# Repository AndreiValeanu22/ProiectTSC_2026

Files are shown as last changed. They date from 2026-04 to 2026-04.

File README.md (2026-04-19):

# InkTime – Proiect TSC 2026

## Rezumat

Acest depozit conține schematica nativă, placa de circuit imprimat, livrabilele de manufacturare, materialele mecanice parțiale și documentația vizuală pentru dispozitivul **InkTime**, aliniate structurii cerute în ghidul de proiect de pe [OCW – Proiect 2026](https://ocw.cs.pub.ro/courses/tsc/proiect2026).

## Galerie imagini

Capturile de mai jos sunt versiunile din directorul `Images/` și se afișează direct în pagina README pe GitHub.

### Schematică (două zone)

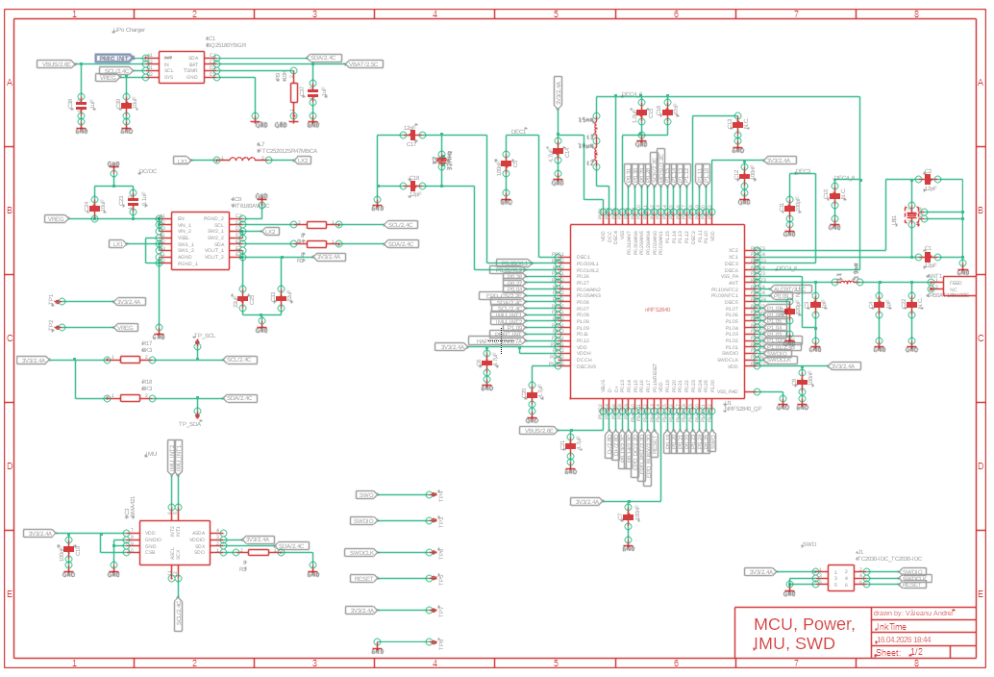
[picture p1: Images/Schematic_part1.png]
Fragment schematică – partea 1


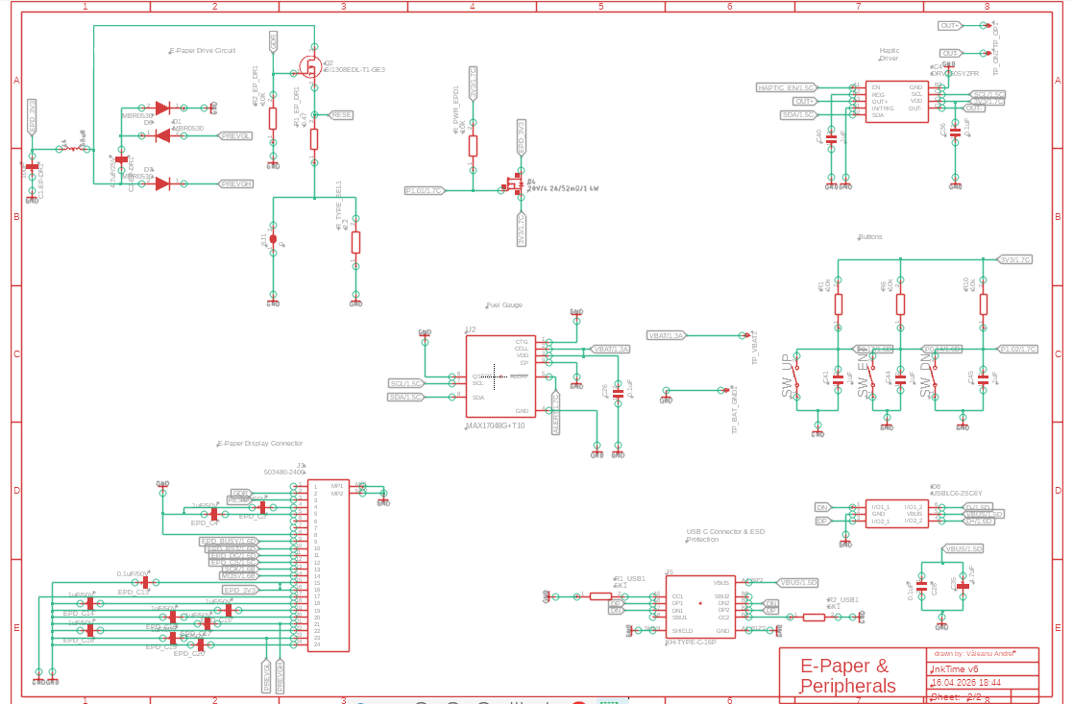
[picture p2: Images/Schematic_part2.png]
Fragment schematică – partea 2


### Placă de circuit imprimat

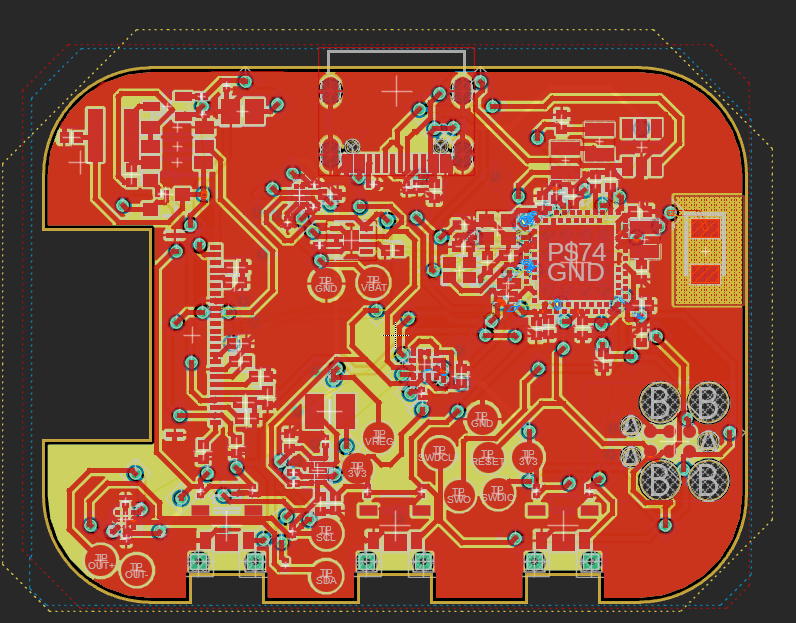
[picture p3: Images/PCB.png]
Vedere PCB


### Previzualizări 3D

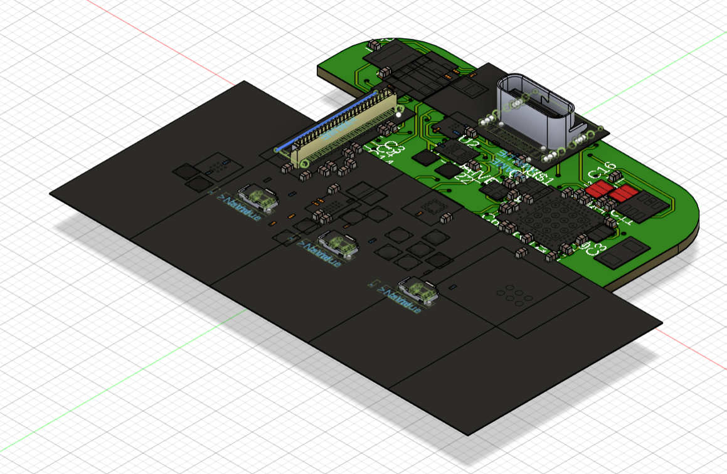
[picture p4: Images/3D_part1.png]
Previzualizare 3D – partea 1


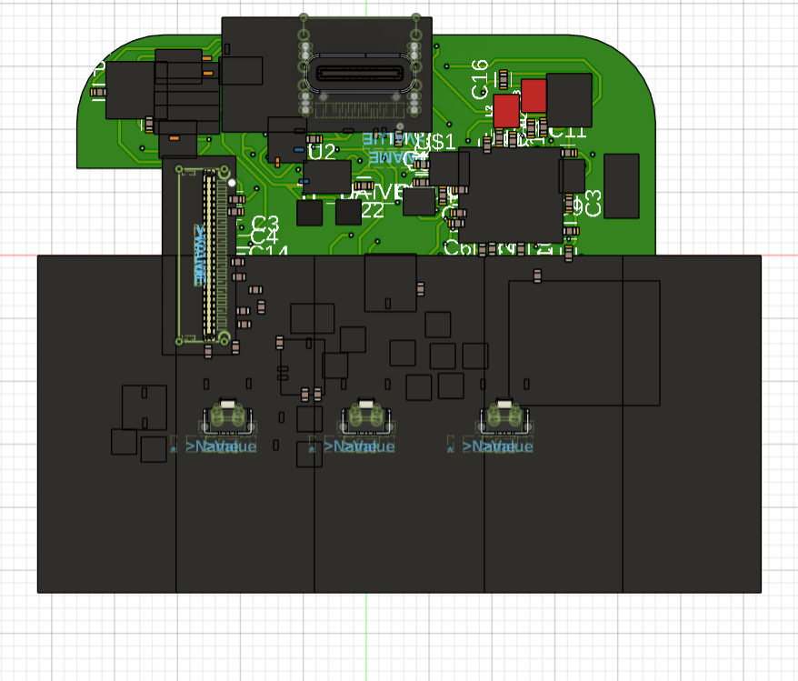
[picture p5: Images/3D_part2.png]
Previzualizare 3D – partea 2


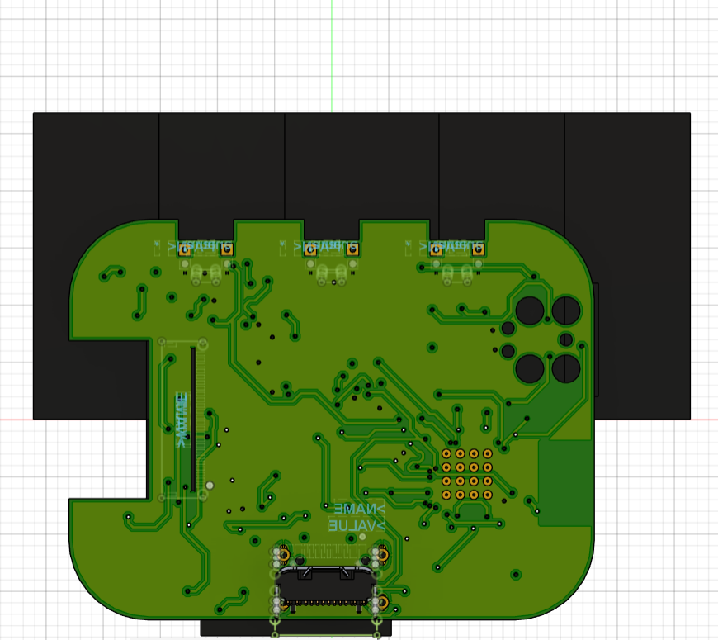
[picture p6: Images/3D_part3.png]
Previzualizare 3D – partea 3


## Conformitate cu structura de încărcare (OCW)

| Cerință OCW | Conținut în acest depozit |
|---|---|
| `Hardware/` – schematic `.sch` | `ProjectTSCEtapa1.sch` |
| `Hardware/` – placă `.brd` | `InkTime v6_PCB_Partea2.brd` |
| `Hardware/` – print schematic `.pdf` | `InkTime_Schematic.pdf` (compus din capturile din `Images/`) |
| `Manufacturing/` – `gerbers.zip` | `gerbers.zip` (vezi secțiunea *Gerber și export CAM*; include cupru/profil/găuri din `.brd` și, opțional, straturi complete din `fusion_export/`) |
| `Manufacturing/` – BOM `.bom` | `InkTime.bom` |
| `Manufacturing/` – Pick&Place `.cpl` | `InkTime.cpl` |
| `Mechanical/` – ansamblu 3D | `ProjectTSCEtapa1.f3z`, `InkTime_Case.f3z`, modele `.STEP` pentru componente, `InkTime v6_PCB_Partea2.3mf` (vezi secțiunea *Modelare 3D*) |
| `Images/` | Randări și capturi (PCB, schematic, previzualizări 3D) |
| `LICENSE`, `README.md` | Prezente |

### Fișierul `InkTime.fbrd` din `Hardware/`

`InkTime.fbrd` este **fișierul de referință** furnizat prin arhiva OCW pentru recomandări de amplasament mecanic; **nu** înlocuiește proiectul de placă editabil. Proiectul de placă livrat pentru evaluare este `InkTime v6_PCB_Partea2.brd`. Fișierul `InkTime.fbrd.brd`, care genera confuzie în review (nu corespundea unui flux clar schematic → placă), a fost **eliminat** din depozit.

## Structura directoarelor

- `Hardware/` – schematic, placă, PDF-ul schemei.
- `Manufacturing/` – `gerbers.zip`, `InkTime.bom`, `InkTime.cpl`, directorul `fusion_export/` pentru exportul CAM din Fusion (vezi mai jos).
- `Mechanical/` – proiecte Fusion (`.f3z`), model 3MF al PCB-ului, modele STEP pentru componente (ex.: conector USB-C, celulă baterie).
- `Images/` – capturi pentru documentație și pentru compunerea PDF-ului schemei.
- `tools/` – scriptul de generare a livrabilelor de manufacturare și a PDF-ului schemei.

## Gerber și export CAM (cerință OCW)

Conform [ghidului de proiect OCW](https://ocw.cs.pub.ro/courses/tsc/proiect2026), arhiva **`gerbers.zip`** trebuie să conțină setul de fișiere Gerber/Excellon folosit la producție (cupru pe toate straturile, mască, pastă, serigrafie, profil, găuri), generate de obicei prin **CAM Processor** din Fusion Electronics, cu fișierul de reguli DRC indicat la curs.

### Cum obții un `gerbers.zip` complet

1. În **Fusion Electronics**, deschide placa și rulează exportul Gerber/Drill conform [tutorialului OCW pentru Gerber](https://ocw.cs.pub.ro/courses/tsc/proiect2026) (meniul de generare CAM din documentația cursului).
2. Copiază **toate** fișierele rezultate (`.gbr`, `.gtl`, `.gbl`, `.gts`, `.gbs`, `.gtp`, `.gko`, `.drl` etc.) în directorul  
   **`Manufacturing/fusion_export/`** din acest depozit (poți păstra denumirile implicite ale Fusion).
3. Din rădăcina depozitului rulează:  
   `python tools/build_ocw_deliverables.py`  
   Scriptul construiește `gerbers.zip` astfel: **mai întâi** include tot ce se află în `fusion_export/`; **apoi** completează doar fișierele lipsă (ex.: straturi de cupru/profil/găuri) din parsarea XML a fișierului `.brd`, dacă Fusion nu a emis deja un fișier cu același nume. Astfel, după ce plasezi exportul CAM, arhiva reflectă **prioritar** setul oficial Fusion, aliniat cerințelor OCW.

Dacă `fusion_export/` este gol, arhiva conține doar livrabilele derivate automat din `.brd` (util pentru verificare rapidă, fără mască/pastă/silk explicite).

## Diagramă bloc (arhitectură hardware)

```mermaid
flowchart LR
  subgraph Alimentare
    USB[USB-C + protecție ESD]
    BAT[Baterie Li-ion]
    IC1[BQ25180 – încărcare]
    IC9[RT6160 – buck-boost]
  end
  subgraph Aplicație
    U1[nRF52840]
    ANT[Antenă 2,45 GHz]
    J3[Conector e-paper]
    IC3[BMA423 – IMU]
    IC4[DRV2605 – driver haptic]
    U2[MAX17048 – fuel gauge]
  end
  USB --> U1
  BAT --> IC1
  IC1 --> U2
  IC9 --> U1
  U1 --> ANT
  U1 --> J3
  U1 --> IC3
  U1 --> IC4
  U1 --> U2
```

## Descriere hardware (rezumat funcțional)

Microcontrolerul principal **nRF52840** (U1) asigură procesarea, conectivitatea **Bluetooth Low Energy** prin pinul dedicat de RF către antena Johanson, interfața **USB** (D+/D−) pentru programare și alimentare de la port, un magistrală **I²C** comună pentru senzori și periferice (încărcător BQ25180, convertoare, MAX17048, BMA423, DRV2605), precum și un port **SPI** (semnalele `SCK` / `MOSI` și liniile de control) către conectorul **Molex 503480-2400** (J3) al afișajului e-paper. Lanțul de alimentare include încărcarea bateriei (IC1), monitorizarea celulei (U2) și reglarea tensiunii de sistem (IC9), conform schemei `ProjectTSCEtapa1.sch`.

## BOM orientativ (module principale)

Tabelul de mai jos indică **componente-reper**; pentru lista completă a pieselor și a footprint-urilor folosiți `Manufacturing/InkTime.bom` (regenerabil). Linkurile către JLCPCB folosesc căutarea după cod articol; datasheet-urile sunt la producător.

| Rol | Piesă (din schemă) | Căutare JLCPCB | Datasheet |
|-----|---|---|---|
| MCU + radio BLE | nRF52840 (U1) | [Căutare „nRF52840”](https://jlcpcb.com/parts/componentSearch?searchTxt=nRF52840) | [Nordic Semiconductor](https://www.nordicsemi.com/products/nrf52840) |
| Încărcare baterie | BQ25180YBGR (IC1) | [Căutare „BQ25180”](https://jlcpcb.com/parts/componentSearch?searchTxt=BQ25180) | [Texas Instruments](https://www.ti.com/product/BQ25180) |
| Buck-boost | RT6160AWSC (IC9) | [Căutare „RT6160”](https://jlcpcb.com/parts/componentSearch?searchTxt=RT6160) | [Richtek](https://www.richtek.com/) |
| IMU | BMA423 (IC3) | [Căutare „BMA423”](https://jlcpcb.com/parts/componentSearch?searchTxt=BMA423) | [Bosch Sensortec](https://www.bosch-sensortec.com/media/datasheets/bst-bma423-ds000.pdf) |
| Fuel gauge | MAX17048G+T10 (U2) | [Căutare „MAX17048”](https://jlcpcb.com/parts/componentSearch?searchTxt=MAX17048) | [Analog Devices](https://www.analog.com/en/products/max17048.html) |
| Driver haptic | DRV2605YZFR (IC4) | [Căutare „DRV2605”](https://jlcpcb.com/parts/componentSearch?searchTxt=DRV2605) | [Texas Instruments](https://www.ti.com/product/DRV2605) |
| Protecție USB | USBLC6-2SC6Y (D8) | [Căutare „USBLC6”](https://jlcpcb.com/parts/componentSearch?searchTxt=USBLC6-2SC6Y) | [STMicroelectronics](https://www.st.com/en/protection-ics/usblc6-2sc6y.html) |
| Conector e-paper | 503480-2400 (J3) | [Căutare „503480-2400”](https://jlcpcb.com/parts/componentSearch?searchTxt=503480-2400) | [Molex – căutare serie](https://www.molex.com/molex/products/search?q=503480-2400) |

## Alocare funcțională a pinilor nRF52840 (U1)

Tabelul rezumă legături **esențiale** extrase din `ProjectTSCEtapa1.sch`; pentru decodarea completă a pad-urilor BGA consultați PDF-ul schemei și fișierul `.sch`.

| Funcțiune | Pin GPIO / dedicat (etichetă în schemă) | Observații |
|---|---|---|
| USB date | `D+`, `D−` | Stivă USB 2.0 integrată în nRF52840 |
| Alimentare USB | `VBUS` | Detecție / alimentare de la conector |
| Depanare SWD | `SWDIO`, `SWDCLK` | Programare și debug |
| Reset | `P0.18` (RESET) | Linie de reset a sistemului |
| RF antenă | `ANT` | Conexiune la rețeaua de adaptare și antenă 2,45 GHz |
| SPI e-paper – ceas | `P0.02` | Semnal `SCK` |
| SPI e-paper – date | `P0.03` | Semnal `MOSI` |
| E-paper – selecție | `P0.05` | `EPD_CS` |
| E-paper – control | `P0.15`, `P0.16`, `P0.17` | Respectiv `EPD_DC`, `EPD_RST`, `EPD_BUSY` |
| I²C periferice | `P0.06` (SDA), `P0.07` (SCL) | Magistrală partajată (încărcător, IMU, gauge, DRV2605 etc.) |
| Întreruperi IMU | `P0.08`, `P1.08` | `IMU_INT1`, `IMU_INT2` |
| Cristal HF | `XC1`, `XC2` | Oscilator 32 MHz pentru radio |

## Justificări tehnice și răspuns la observațiile din review

Secțiunea următoare documentează, în mod explicit, starea **ERC/DRC**, limitările la **modelarea 3D** și, pentru transparență, **via stitching** (ce apare concret în layout) versus **via fencing** (definiție de referință din documentație / curs).

### Schematică și ERC (Electrical Rule Check)

Schema electrică este **funcțional completă** în sensul fluxurilor de alimentare, de date și de interfețe prevăzute de tema InkTime. La rularea **ERC** în mediul Autodesk Fusion / Eagle, rezultatul curent este **0 erori** și **44 avertismente**.

În cadrul laboratorului a fost comunicat faptul că, pentru această temă, **ordinul de mărime a avertismentelor ERC** se situează în mod tipic în jurul valorii de **40** (alți colegi au raportat, de exemplu, **41** de avertismente). În evoluția propriului proiect, au fost înregistrate **43**, apoi **44** de avertismente, după ajustări minore de bibliotecă și de etichetare. Variația cu **una–două unități** față de media grupei se încadrează, din perspectivă inginerească, în **aceeași clasă de severitate**: majoritatea mesajelor sunt **neblocante** (ex.: atribute de catalog incomplete, recomandări de denumire, conexiuni marcate ca „not connected” acolo unde pachetul o permite, sau reguli conservative ale verificatorului). **Nu au fost ignorate erori ERC critice**; avertismentele rămân documentate pentru transparență și pot fi grupate pe categorii (alimentări, biblioteci online, NC) într-o iterație ulterioară de curățare a schemei, fără a altera topologia electrică aprobată.

### Placă (PCB) și DRC (Design Rule Check)

Verificarea **DRC** cu setul de reguli indicat în cadrul cursului raportează, în stadiul curent al plăcii, următoarele categorii (valorile reflectă ultima centralizare folosită în review):

| Categorie DRC | Număr de încălcări | Interpretare sumară |
|---|---:|---|
| Overlap | 65 | Suprapuneri în principal între **pad-uri / pastile de pastă / zone fine** la densitate mare (capsule 0201, sub BGA), uneori exacerbate de toleranțele stricte ale fișierului de reguli. |
| Drill clearance | 3 | Spațiere insuficientă față de **gaură / via** în câteva zone critice. |
| Clearance (cupru) | 14 | Violări de **distanță minimă între obiecte de cupru** (trasee, poligoane, keepout), inclusiv zone cu geometrie compresată. |
| Board outline clearance | 2 | Obiecte apropiate de **conturul mecanic** al plăcii (inclusiv în proximitatea decupărilor pentru antenă sau a alinierii mecanice cu carcasa). |
| Air wires | 26 | Conexiuni **nerealizate complet** în editor (rutare incompletă). |

**Poziția de proiectare.** Eliminarea completă a acestor observații ar impune, în multe locuri, **relocări majore de componente**, subțierea suplimentară a traseelor sub pragul recomandat pentru **putere (0,3 mm)** sau relaxarea keepout-ului antenei, ceea ce contravine obiectivelor de **fiabilitate** și de **conformitate RF** din temă. În practică, **corectarea iterativă** a suprapunerilor și a clearance-urilor devine rapid **neconvexă**: fiecare mică mutare propagă noi conflicte în zonele BGA și în coridorul USB–butoane. Din acest motiv, un subset de încălcări este **acceptat temporar** ca **datorie tehnică documentată**, iar remedierea completă este planificată prin: (1) relaxarea controlată a unor reguli doar acolo unde cursul permite explicit excepții (ex.: note OCW privind anumite dimensionări); (2) **finalizarea rutării** pe straturi interioare și prin optimizarea ordinii de fan-out de sub BGA; (3) revizuirea **stitching**-ului de masă acolo unde pad-urile intră în conflict mecanic cu plasamentul via-urilor.

**Airwires (26).** Menținerea concomitentă a **grosimilor de alimentare**, a **izolației** față de planurile de masă și a **accesului mecanic** (USB, butoane, conector e-paper) limitează numărul de canale de rutare disponibile; unele net-uri rămân astfel **intenționat neînchise** în editor până la o rundă dedicată de **rip-up / re-route**, pentru a nu compromite traseele deja validate din punct de vedere al curentului și al integrității semnalului.

### Modelare 3D și ansamblu STEP unificat

Conform cerințelor OCW, livrabilul ideal include un **STEP unificat** (vedere explodată sau ansamblu complet: PCB + baterie + display + carcasă). În acest depozit, **acest fișier unificat lipsește**.

### Via stitching și via fencing (clarificare pentru acest layout)

În documentație apar adesea împreună **via stitching** și **via fencing** (*via shielding*). În **proiectul InkTime**, ceea ce apare **concret** în placă sunt în primul rând **vias care leagă rețeaua de masă (`GND`) între straturi fizice diferite** (de exemplu cupru pe **Top**, plan de masă pe stratul interior denumit în fișier **Route2**, cupru pe **Bottom**). Acest comportament intră la **via stitching**: **același net electric** (masă) este „cusut” **vertical** prin vias între **layere cu denumiri diferite** în editor. **Nu** este necesar ca două straturi să aibă **același nume** în fișierul `.brd`; este necesar ca **același potențial de referință** să fie continuu între straturi, ceea ce reduce impedanța de masă și ajută la disiparea termică. Referință: [Autodesk – Understanding the Power of Stitching Vias in PCB Design](https://www.autodesk.com/products/fusion-360/blog/understanding-the-power-of-via-stitching-in-pcb-design/).

**Via fencing** (sau *via shielding*) desemnează, în literatură, **rânduri de vias** plasate **de-a lungul unui traseu** sau în jurul unei zone **RF**, pentru ecranare EMI — geometria urmează **linia semnalului**, nu umplerea unui poligon de masă. Definiție și contrast formal: [Altium – Via Stitching & Via Shielding](https://www.altium.com/documentation/altium-designer/pcb/via-stitching-via-shielding).

| Aspect | Via stitching | Via fencing (shielding) |
|---|---|---|
| Aranjament | Grilă / rețea pe zone mari de cupru (masă) | Rând(uri) paralele, urmărind traseul sau perimetrul |
| Obiect leagat | **Același net** (ex. `GND`) pe **straturi diferite** | Traseu sau zonă sensibilă (ex. RF), cu gard de referință |
| Confuzie frecventă | Nu înseamnă „două layere cu același nume în Eagle” | Nu este același lucru cu un **via obișnuit** care doar traversează placa între două trasee de semnal |
| În proiectul InkTime | **Da**, prin **vias de continuitate pentru masă** între straturi (GND între Top / Route2-GND / Bottom etc.). | **Nu este documentat aici** ca „gard” dedicat de vias pe conturul fiecărui traseu RF; zona antenă este tratată în primul rând prin **keepout** și rutare conform temei; fencing-ul rămâne **reper de curs** pentru design RF avansat. |

**Rezumat:** *stitching* = **cusătură verticală a masei** între layere; *fencing* = **gard** pe lângă traseu; în acest depozit, **afirmația verificabilă** este cea despre **stitching-ul de masă**; **fencing-ul strict** este explicat pentru **comparare**, nu ca să se presupună automat același nivel de implementare ca în exemplele CAD din linkuri.

## Modelare 3D (ansamblu complet)

Ansamblul explodat complet (PCB + baterie + display + carcasă), în format **STEP** unificat, **nu este inclus** momentan. Depozitul conține, pentru continuitate:

- proiecte Fusion (`ProjectTSCEtapa1.f3z`, `InkTime_Case.f3z`);
- export 3MF al PCB-ului cu componente (`InkTime v6_PCB_Partea2.3mf`);
- modele **STEP** pentru subansamble și componente (denumiri derivate din catalog; consultați tabelul de mai jos).

| Fișier | Rol presupus în proiect |
|---|---|
| `KH-TYPE-C-16P--3DModel-STEP-269445.STEP` | Model 3D conector USB-C |
| `EVP-AKE31A--3DModel-STEP-56544.STEP` | Model 3D baterie / celulă (EVP-AKE31A) |
| `5034802400--3DModel-STEP-56544.STEP` | Model 3D componentă suplimentară (cod producător) |
| `InkTime v6_PCB_Partea2.3mf` | PCB cu componente (3MF) |
| `ProjectTSCEtapa1.f3z`, `InkTime_Case.f3z` | Proiecte Fusion (ansamblu parțial / carcasă) |

## Note de proiectare și decizii documentate

### Ajustări la nivelul butoanelor

Amplasamentul și geometria **butoanelor** au fost **revizuite incremental** pe stratul de placă, în corelație cu recomandările mecanice din materialele OCW, cu scopul de a **atenua conflictele dimensionale** și de a **reduce severitatea unor erori raportate de DRC** (ex.: depășiri de contur sau interferențe cu zonele de toleranță ale mufei USB-C). Modificările au fost limitate la domeniul necesar menținerii alinierii funcționale cu carcasa, fără a altera schema logică a sistemului.

### Rutare incompletă (airwires)

Procesul de rutare este **în desfășurare**: în stadiul curent al plăcii există **douăzeci și șase de conexiuni nerealizate complet** (afișate de editor ca *airwires*). Cauza principală este **densitatea foarte ridicată** a interconexiunilor în proximitatea circuitelor integrate în capsulă fină (inclusiv sub zona BGA), coroborată cu **restricții severe de spațiu** pe straturile exterioare și cu necesitatea respectării lățimilor minime pentru alimentare și a keepout-ului antenei. Detalii suplimentare și legătura cu raportul DRC se găsesc în secțiunea *Placă (PCB) și DRC*.

## Note de proiect (PCB)

- Patru straturi: Top și Bottom pentru semnale, **Route2** ca plan de masă, **Route15** ca plan de alimentare (conform denumirilor din fișierul `.brd`).
- Trasee de putere: **0,3 mm**; semnale: **minimum 0,15 mm**.
- Antenă la marginea plăcii, cu **keepout** (fără cupru) pe straturile relevante.
- Condensatoare de decuplare cât mai aproape de pini de alimentare.
- Componente plasate exclusiv pe **TOP**.
- **Via stitching** (vias pentru **GND** între **straturi fizice diferite**; layerele nu trebuie să aibă același nume în `.brd`), conform secțiunii dedicate; **via fencing** strict este doar **explicat** acolo, nu echivalat cu simplele vias de masă.

## Rezumat numeric ERC / DRC

| Verificare | Rezultat |
|---|---|
| ERC | **0 erori**, **44 avertismente** |
| DRC – Overlap | **65** |
| DRC – Drill clearance | **3** |
| DRC – Clearance (cupru) | **14** |
| DRC – Board outline clearance | **2** |
| DRC – Air wires | **26** |

Valorile trebuie re-verificate după fiecare modificare a plăcii sau după re-exportul CAM.

## Plan de verificare

- ERC: gruparea avertismentelor pe categorii (bibliotecă, NC, alimentări) și eliminarea celor care nu afectează funcția.
- DRC cu fișierul de reguli OCW; iterare pe **overlap** și **clearance** acolo unde nu se sacrifică RF sau puterea.
- Verificare keepout în zona antenei; eventual **via fencing** dedicat doar dacă se adoptă explicit în layout (reper RF din curs).
- Verificare rutare de putere (0,3 mm) și continuitate plan de masă (**via stitching**).
- Regenerare livrabile: `python tools/build_ocw_deliverables.py`.

## Regenerarea livrabilelor

Din rădăcina depozitului, cu Python 3 și pachetele `gerbonara`, `reportlab`, `pillow` instalate. După ce ai plasat exportul CAM în `Manufacturing/fusion_export/`, rulează:

```bash
python tools/build_ocw_deliverables.py
```

Comanda actualizează `InkTime.bom`, `InkTime.cpl`, `InkTime_Schematic.pdf` și reconstruiește `gerbers.zip` conform regulilor de fuziune descrise mai sus.

## Licență

Vezi `LICENSE` (MIT).


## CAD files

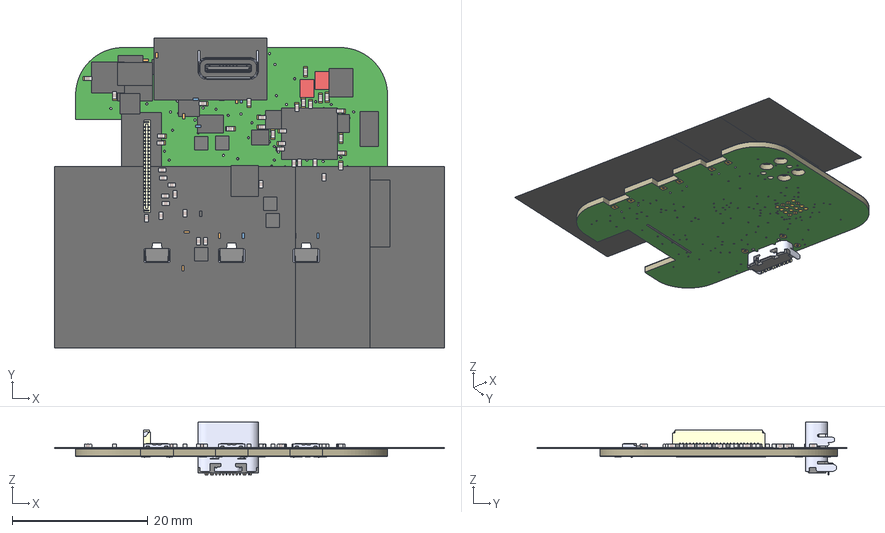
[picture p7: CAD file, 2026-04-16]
Mechanical/InkTime v6_PCB_Partea2.3mf
57.5 x 45.7 x 7.81 mm
Board
CopperHoles

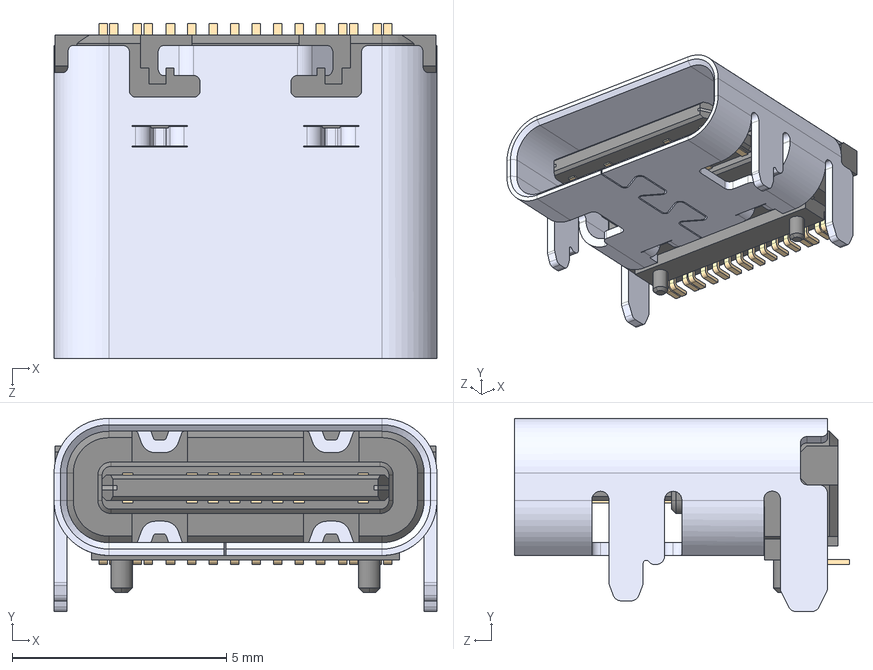
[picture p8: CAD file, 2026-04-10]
Mechanical/KH-TYPE-C-16P--3DModel-STEP-269445.STEP
8.94 x 4.51 x 7.81 mm

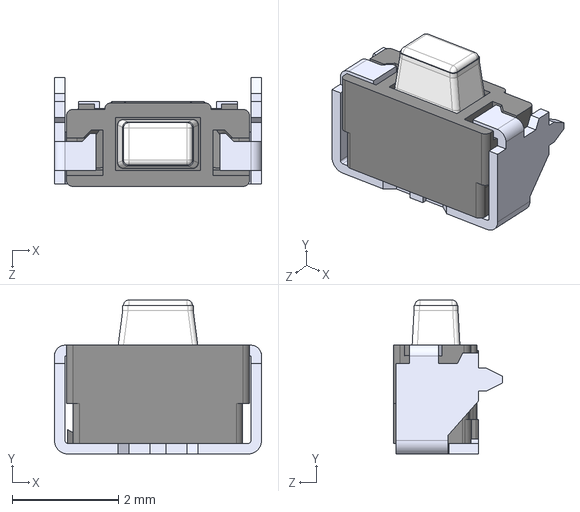
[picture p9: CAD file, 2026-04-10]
Mechanical/EVP-AKE31A--3DModel-STEP-56544.STEP
3.90 x 2.90 x 2.05 mm

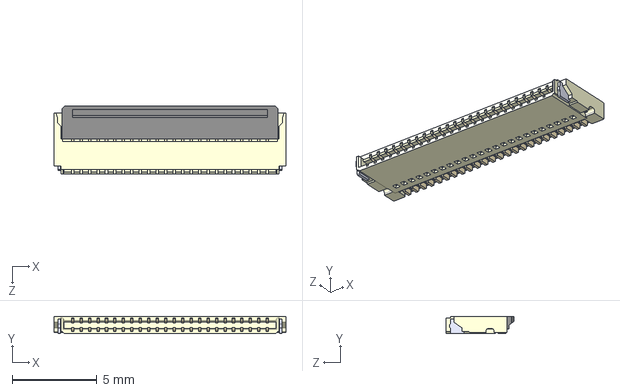
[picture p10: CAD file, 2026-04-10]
Mechanical/5034802400--3DModel-STEP-56544.STEP
13.7 x 1.02 x 4.00 mm

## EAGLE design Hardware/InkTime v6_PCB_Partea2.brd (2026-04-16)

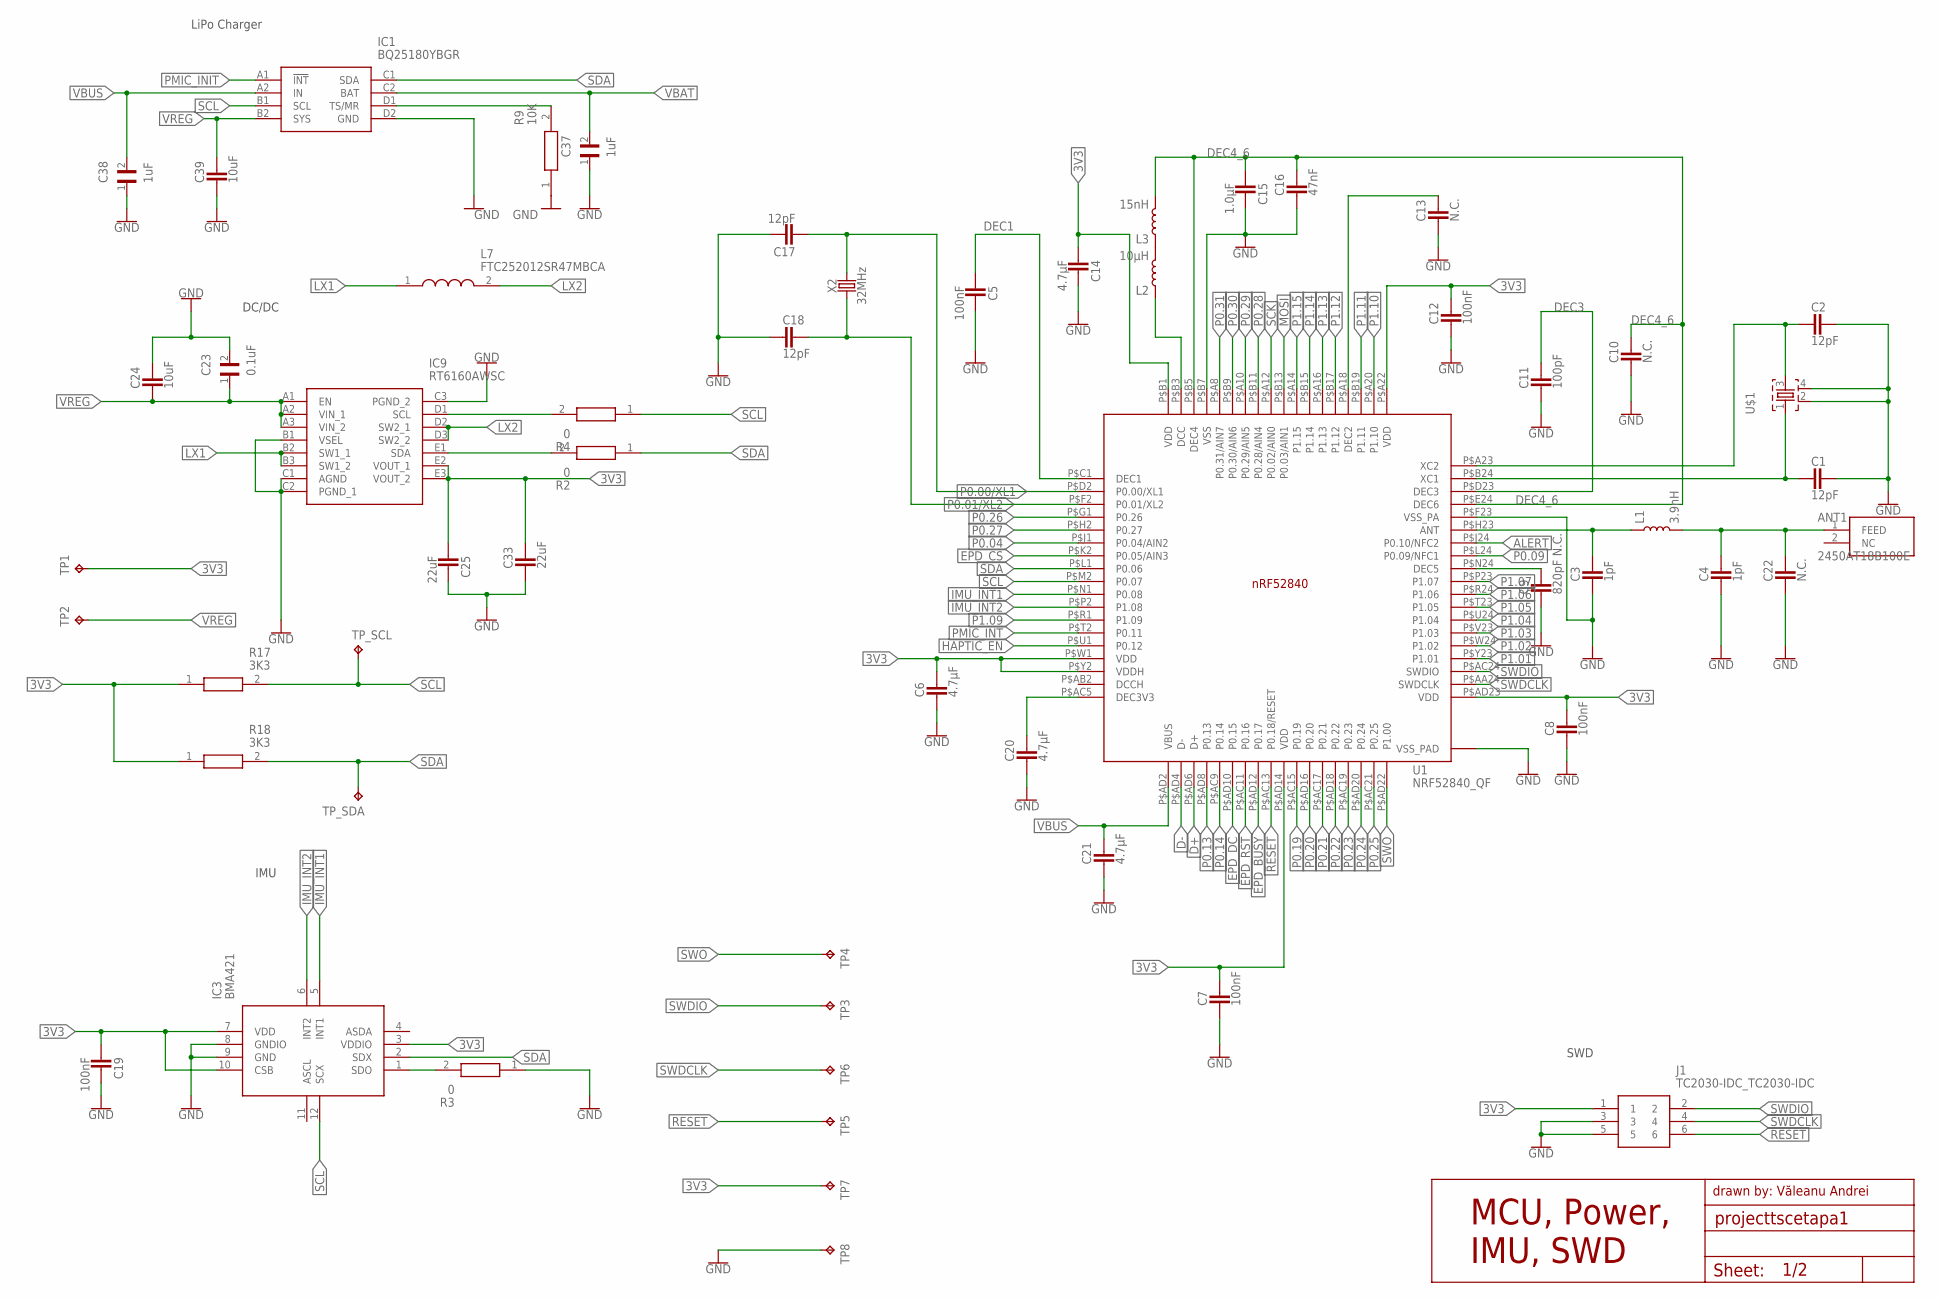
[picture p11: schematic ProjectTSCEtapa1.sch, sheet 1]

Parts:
ANT1: 2450AT18B100E; 2450AT18B100E_ANTC3216X140N
C1, C2, C17, C18: 12pF; CAPC1005X60
C3, C4: 1pF; CAPC1005X60
C5, C7, C8, C12, C19: 100nF; CAPC1005X60
C6, C14, C20, C21: 4.7μF; CAPC1005X60
C9: 820pF N.C.; CAPC1005X60
C10, C13, C22: N.C.; CAPC1005X60
C11: 100pF; CAPC1005X60
C15: 1.0μF; CAPC1005X60
C16: 47nF; CAPC1005X60
C23: 0.1uF; GRM011R60J152KE01L_1_0201
C24, C39: 10uF; CAPC1005X60
C25, C33: 22uF; CAPC1005X60
C37, C38: 1uF; GRM011R60J152KE01L_1_0201
IC1: BQ25180YBGR; BQ25180YBGR_BGA8C40P2X4_100X155X50
IC3: BMA421; BMA423_BMA423
IC9: RT6160AWSC; RT6160AWSC_BGA15C40P3X5_140X230X60
J1: TC2030-IDC_TC2030-IDC; TC2030-IDC_TC2030IDC
L1: 3.9nH; 0805-WIDE
L2: 10μH; 0805-WIDE
L3: 15nH; 0805-WIDE
L7: FTC252012SR47MBCA; MLP2016SR47MT0S1_INDC2016X100N
R2, R3, R4: 0; CPF0201D7K68C1_0201
R9: 10K; CPF0201D7K68C1_0201
R17, R18: 3K3; CPF0201D7K68C1_0201
TP1, TP2, TP3, TP4, TP5, TP6, TP7, TP8: HECTOR_WATCH_1_TPTP20R; HECTOR_WATCH_1_TP20R
TP_SCL: HECTOR_WATCH_1_TPTP20R; HECTOR_WATCH_1_TP20R
TP_SDA: HECTOR_WATCH_1_TPTP20R; HECTOR_WATCH_1_TP20R
U1: NRF52840_QF; NORDIC_NRF_4_AQFN50P700X700X85_HS-74N
U$1: NORDIC_NRF_XTAL_32MHZ; NORDIC_NRF_BT-XTAL_2016_N
X2: 32MHz; CRYSTAL-SMD-2.0X1.6MM

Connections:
3V3: C6.1, C7.1, C8.1, C12.1, C14.2, C19.2, C25.2, C33.1, IC3.3 (VDDIO), IC3.7 (VDD), IC3.10 (CSB), IC9.E2 (VOUT_1), IC9.E3 (VOUT_2), J1.1, R17.1, R18.1, TP1.TP, TP7.TP, U1.P$A22 (VDD), U1.P$AD14 (VDD), U1.P$AD23 (VDD), U1.P$B1 (VDD), U1.P$W1 (VDD), U1.P$Y2 (VDDH); also elsewhere on the board
ALERT: U1.P$J24 (P0.10/NFC2); also elsewhere on the board
D+: U1.P$AD6 (D+); also elsewhere on the board
D-: U1.P$AD4 (D-); also elsewhere on the board
DEC1: C5.2, U1.P$C1 (DEC1)
DEC3: C11.1, U1.P$D23 (DEC3)
DEC4_6: C10.1, C15.2, C16.1, L3.2, U1.P$B5 (DEC4), U1.P$E24 (DEC6)
EPD_BUSY: U1.P$AD12 (P0.17); also elsewhere on the board
EPD_CS: U1.P$K2 (P0.05/AIN3); also elsewhere on the board
EPD_DC: U1.P$AD10 (P0.15); also elsewhere on the board
EPD_RST: U1.P$AC11 (P0.16); also elsewhere on the board
GND: C1.1, C2.1, C3.2, C4.2, C5.1, C6.2, C7.2, C8.2, C9.2, C10.2, C11.2, C12.2, C13.2, C14.1, C15.1, C16.2, C17.1, C18.2, C19.1, C20.2, C21.2, C22.2, C23.2, C24.1, C25.1, C33.2, C37.1, C38.1, C39.2, IC1.D2 (GND), IC3.8 (GNDIO), IC3.9 (GND), IC9.B1 (VSEL), IC9.C1 (AGND), IC9.C2 (PGND_1), IC9.C3 (PGND_2), J1.3, J1.5, R3.1, R9.1, TP8.TP, U1.P$74 (VSS_PAD), U1.P$75 (VSS_PAD), U1.P$76 (VSS_PAD), U1.P$77 (VSS_PAD), U1.P$78 (VSS_PAD), U1.P$79 (VSS_PAD), U1.P$80 (VSS_PAD), U1.P$81 (VSS_PAD), U1.P$82 (VSS_PAD), U1.P$83 (VSS_PAD), U1.P$84 (VSS_PAD), U1.P$85 (VSS_PAD), U1.P$86 (VSS_PAD), U1.P$87 (VSS_PAD), U1.P$88 (VSS_PAD), U1.P$89 (VSS_PAD), U1.P$90 (VSS_PAD), U1.P$B7 (VSS), U1.P$F23 (VSS_PA), U$1.2, U$1.4; also elsewhere on the board
HAPTIC_EN: U1.P$U1 (P0.12); also elsewhere on the board
IMU_INT1: IC3.5 (INT1), U1.P$N1 (P0.08)
IMU_INT2: IC3.6 (INT2), U1.P$P2 (P1.08)
LX1: IC9.B2 (SW1_1), IC9.B3 (SW1_2), L7.1
LX2: IC9.D2 (SW2_1), IC9.D3 (SW2_2), L7.2
MOSI: U1.P$B13 (P0.03/AIN1); also elsewhere on the board
unnamed: IC9.D1 (SCL), R4.2
unnamed: IC9.E1 (SDA), R2.2
unnamed: IC3.1 (SDO), R3.2
unnamed: C3.1, L1.1, U1.P$H23 (ANT)
unnamed: ANT1.1 (FEED), C4.1, C22.1, L1.2
unnamed: IC1.D1 (TS/MR), R9.2
unnamed: C9.1, U1.P$N24 (DEC5)
unnamed: C20.1, U1.P$AC5 (DEC3V3)
unnamed: L2.2, L3.1
unnamed: L2.1, U1.P$B3 (DCC)
unnamed: C13.1, U1.P$A18 (DEC2)
unnamed: C2.2, U1.P$A23 (XC2), U$1.3
unnamed: C1.2, U1.P$B24 (XC1), U$1.1
P0.00/XL1: C17.2, U1.P$D2 (P0.00/XL1), X2.3 (2)
P0.01/XL2: C18.1, U1.P$F2 (P0.01/XL2), X2.1
P0.04: U1.P$J1 (P0.04/AIN2)
P0.09: U1.P$L24 (P0.09/NFC1)
P0.13: U1.P$AD8 (P0.13); also elsewhere on the board
P0.14: U1.P$AC9 (P0.14); also elsewhere on the board
P0.19: U1.P$AC15 (P0.19)
P0.20: U1.P$AD16 (P0.20)
P0.21: U1.P$AC17 (P0.21)
P0.22: U1.P$AD18 (P0.22)
P0.23: U1.P$AC19 (P0.23)
P0.24: U1.P$AD20 (P0.24)
P0.25: U1.P$AC21 (P0.25)
P0.26: U1.P$G1 (P0.26)
P0.27: U1.P$H2 (P0.27)
P0.28: U1.P$B11 (P0.28/AIN4)
P0.29: U1.P$A10 (P0.29/AIN5)
P0.30: U1.P$B9 (P0.30/AIN6)
P0.31: U1.P$A8 (P0.31/AIN7)
P1.01: U1.P$Y23 (P1.01); also elsewhere on the board
P1.02: U1.P$W24 (P1.02); also elsewhere on the board
P1.03: U1.P$V23 (P1.03)
P1.04: U1.P$U24 (P1.04)
P1.05: U1.P$T23 (P1.05)
P1.06: U1.P$R24 (P1.06)
P1.07: U1.P$P23 (P1.07)
P1.09: U1.P$R1 (P1.09)
P1.10: U1.P$A20 (P1.10)
P1.11: U1.P$B19 (P1.11)
P1.12: U1.P$B17 (P1.12)
P1.13: U1.P$A16 (P1.13)
P1.14: U1.P$B15 (P1.14)
P1.15: U1.P$A14 (P1.15)
PMIC_INIT: IC1.A1 (!INT)
PMIC_INT: U1.P$T2 (P0.11)
RESET: J1.6, TP5.TP, U1.P$AC13 (P0.18/RESET)
SCK: U1.P$A12 (P0.02/AIN0); also elsewhere on the board
SCL: IC1.B1 (SCL), IC3.12 (SCX), R4.1, R17.2, TP_SCL.TP, U1.P$M2 (P0.07); also elsewhere on the board
SDA: IC1.C1 (SDA), IC3.2 (SDX), R2.1, R18.2, TP_SDA.TP, U1.P$L1 (P0.06); also elsewhere on the board
SWDCLK: J1.4, TP6.TP, U1.P$AA24 (SWDCLK)
SWDIO: J1.2, TP3.TP, U1.P$AC24 (SWDIO)
SWO: TP4.TP, U1.P$AD22 (P1.00)
VBAT: C37.2, IC1.C2 (BAT); also elsewhere on the board
VBUS: C21.1, C38.2, IC1.A2 (IN), U1.P$AD2 (VBUS); also elsewhere on the board
VREG: C23.1, C24.2, C39.1, IC1.B2 (SYS), IC9.A1 (EN), IC9.A2 (VIN_1), IC9.A3 (VIN_2), TP2.TP

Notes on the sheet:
1/2
Sheet:
MCU, Power, IMU, SWD
drawn by: Văleanu Andrei
LiPo Charger
DC/DC
IMU
SWD

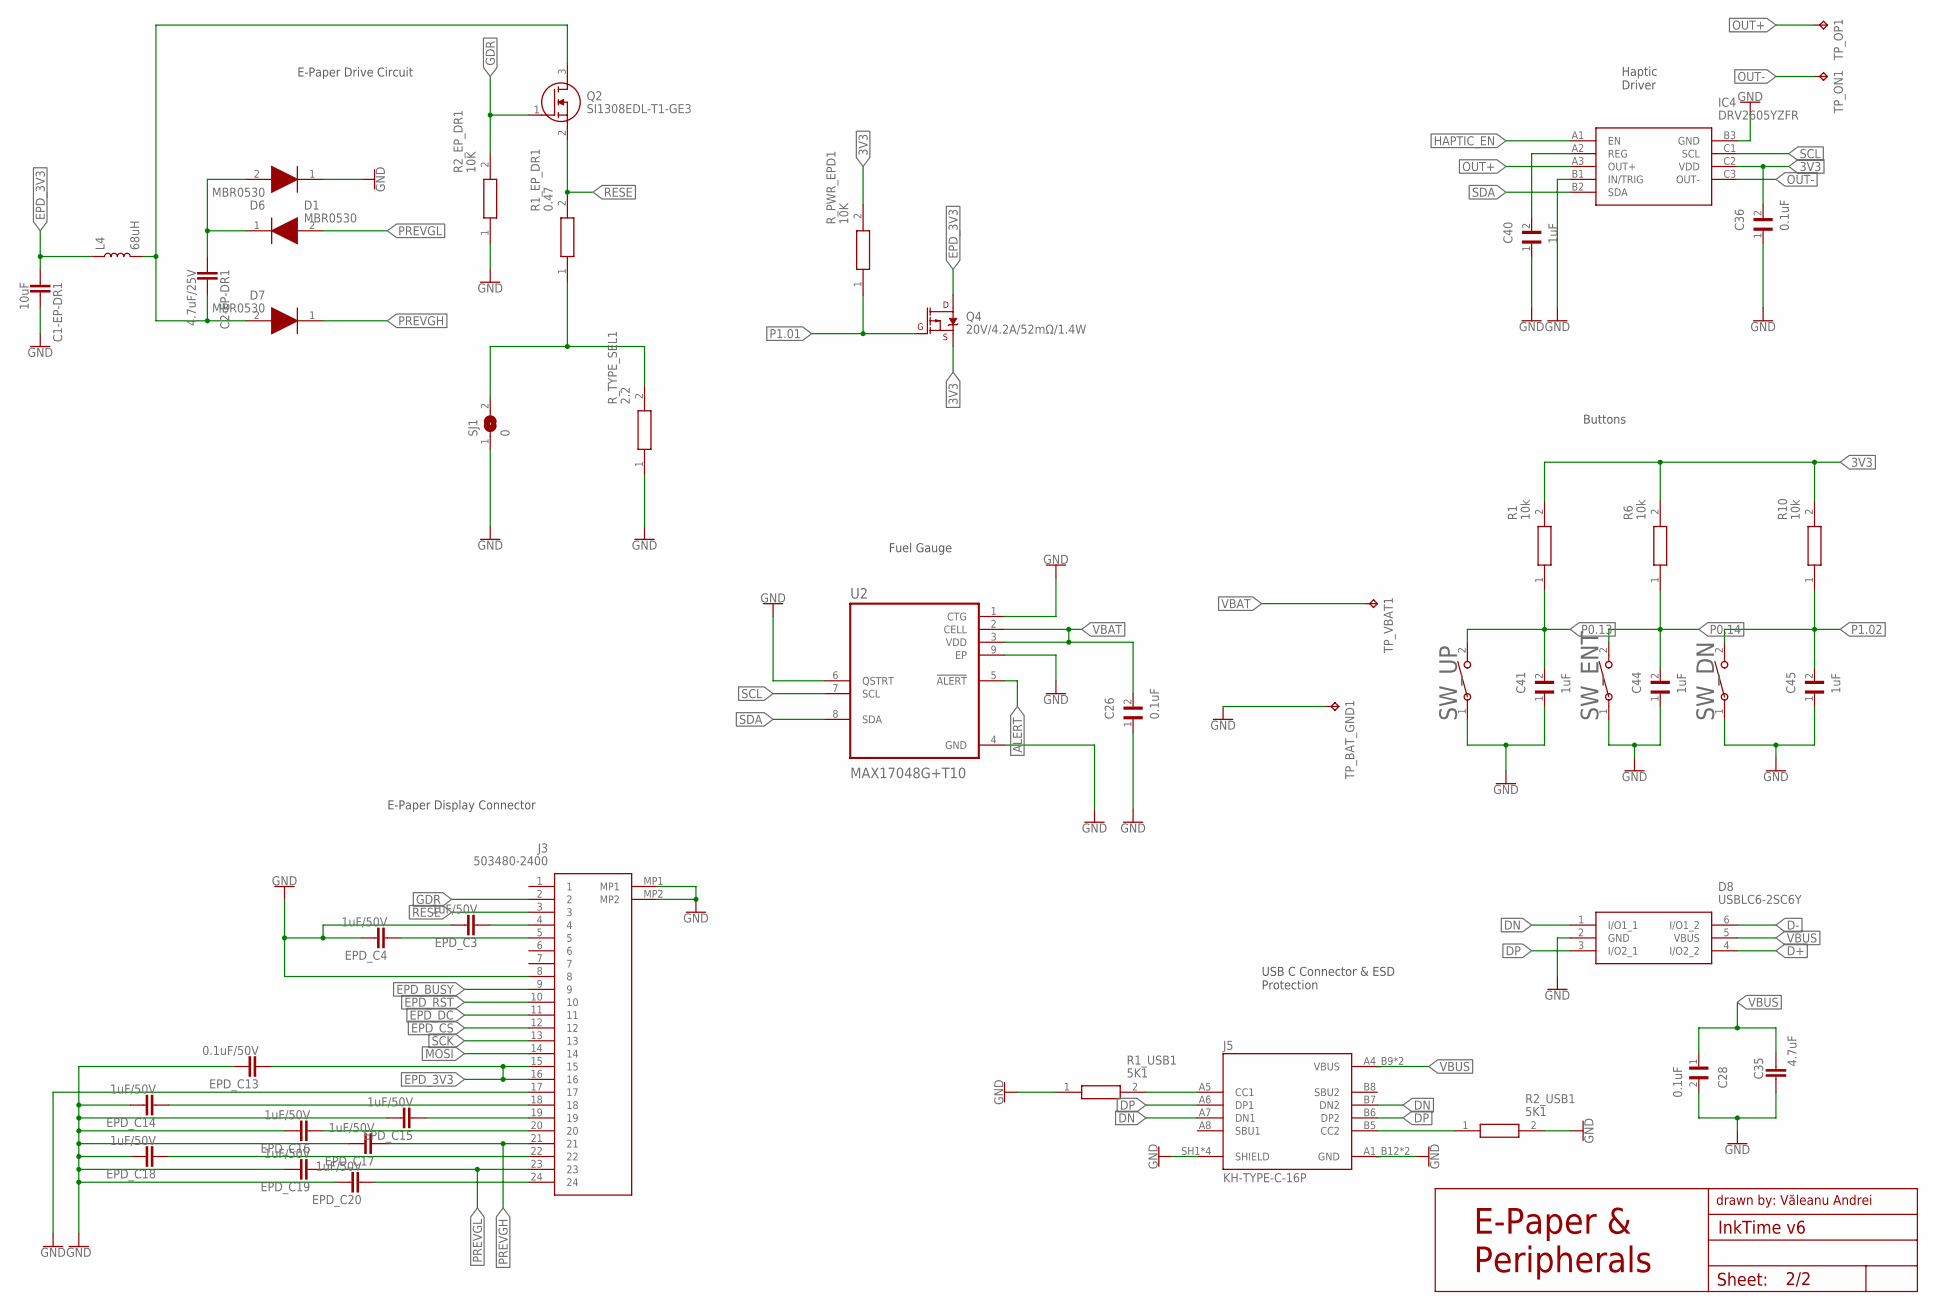
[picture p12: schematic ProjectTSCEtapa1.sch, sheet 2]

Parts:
C1-EP-DR1: 10uF; CAPC1005X60
C2-EP-DR1: 4.7uF/25V; CAPC1005X60
C26, C28, C36: 0.1uF; GRM011R60J152KE01L_1_0201
C35: 4.7uF; CAPC1005X60
C40, C41, C44, C45: 1uF; GRM011R60J152KE01L_1_0201
D1, D6, D7: MBR0530; ESP32_C6_LIBRARY_5_SOD3716X135N
D8: USBLC6-2SC6Y; ESP32_C6_LIBRARY_3_SOT95P280X145-6N
EPD_C3, EPD_C4, EPD_C14, EPD_C15, EPD_C16, EPD_C17, EPD_C18, EPD_C19, EPD_C20: 1uF/50V; CAPC1005X60
EPD_C13: 0.1uF/50V; CAPC1005X60
IC4: DRV2605YZFR; DRV2605YZFR_BGA9C50P3X3_144X144X62
J3: 503480-2400; 503480-2400_5034802400
J5: KH-TYPE-C-16P; KH-TYPE-C-16P_KINGHELM_KH-TYPE-C-16P
L4: 68uH; XFL4020
Q2: SI1308EDL-T1-GE3; ESP32_C6_LIBRARY_6_SOT65P210X110-3N
Q4: 20V/4.2A/52mΩ/1.4W; ESP32_C6_LIBRARY_4_ESP32_C6_LIBRARY_4_ESP32_C6_LIBRARY_4_ES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
R1, R6, R10: 10k; CPF0201D7K68C1_0201
R1_EP_DR1: 0.47; CPF0201D7K68C1_0201
R1_USB1, R2_USB1: 5K1; CPF0201D7K68C1_0201
R2_EP_DR1: 10K; CPF0201D7K68C1_0201
R_PWR_EPD1: 10K; CPF0201D7K68C1_0201
R_TYPE_SEL1: 2.2; CPF0201D7K68C1_0201
SJ1: 0; ESP32_C6_LIBRARY_7_JUMPER_SJ
SW_DN: 2025-10-22_07-23-44_LIBRARY_EVP-AKE31ASW_EVP-AKE3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; 2025-10-22_07-23-44_LIBRARY_SW_EVP-AKE31A_PAN
SW_ENT: 2025-10-22_07-23-44_LIBRARY_EVP-AKE31ASW_EVP-AKE3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; 2025-10-22_07-23-44_LIBRARY_SW_EVP-AKE31A_PAN
SW_UP: 2025-10-22_07-23-44_LIBRARY_EVP-AKE31ASW_EVP-AKE3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; 2025-10-22_07-23-44_LIBRARY_SW_EVP-AKE31A_PAN
TP_BAT_GND1: HECTOR_WATCH_1_TPTP20R; HECTOR_WATCH_1_TP20R
TP_ON1: HECTOR_WATCH_1_TPTP20R; HECTOR_WATCH_1_TP20R
TP_OP1: HECTOR_WATCH_1_TPTP20R; HECTOR_WATCH_1_TP20R
TP_VBAT1: HECTOR_WATCH_1_TPTP20R; HECTOR_WATCH_1_TP20R
U2: MAX17048G+T10; ESP32_C6_LIBRARY_SON50P200X200X80-9N

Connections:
3V3: C36.2, IC4.C2 (VDD), Q4.2 (S), R1.2, R6.2, R10.2, R_PWR_EPD1.2; also elsewhere on the board
3V3/1.7D2: C40.2, IC4.A2 (REG)
ALERT: U2.5 (!ALERT); also elsewhere on the board
D+: D8.4 (I/O2_2); also elsewhere on the board
D-: D8.6 (I/O1_2); also elsewhere on the board
DN: D8.1 (I/O1_1), J5.A7 (DN1), J5.B7 (DN2)
DP: D8.3 (I/O2_1), J5.A6 (DP1), J5.B6 (DP2)
EPD_3V3: C1-EP-DR1.2, EPD_C13.2, J3.15, J3.16, L4.P$1 (1), Q4.3 (D)
EPD_BUSY: J3.9; also elsewhere on the board
EPD_CS: J3.12; also elsewhere on the board
EPD_DC: J3.11; also elsewhere on the board
EPD_RST: J3.10; also elsewhere on the board
GDR: J3.2, Q2.1 (G), R2_EP_DR1.2
GND: C1-EP-DR1.1, C26.1, C28.2, C35.2, C36.1, C40.1, C41.1, C44.1, C45.1, D6.1 (K), D8.2 (GND), EPD_C3.1, EPD_C4.1, EPD_C13.1, EPD_C14.1, EPD_C15.1, EPD_C16.1, EPD_C17.1, EPD_C18.1, EPD_C19.1, EPD_C20.1, IC4.B1 (IN/TRIG), IC4.B3 (GND), J3.8, J3.17, J3.MP1, J3.MP2, J5.A1_B12 (GND), J5.A12_B1 (GND), J5.SH1 (SHIELD), J5.SH2 (SHIELD), J5.SH3 (SHIELD), J5.SH4 (SHIELD), R1_USB1.1, R2_EP_DR1.1, R2_USB1.2, R_TYPE_SEL1.1, SJ1.1, SW_DN.1, SW_ENT.1, SW_UP.1, TP_BAT_GND1.TP, U2.1 (CTG), U2.4 (GND), U2.6 (QSTRT), U2.9 (EP); also elsewhere on the board
HAPTIC_EN: IC4.A1 (EN); also elsewhere on the board
MOSI: J3.14; also elsewhere on the board
unnamed: C2-EP-DR1.1, D7.2 (A), L4.P$2 (2), Q2.3 (D)
unnamed: R1_EP_DR1.1, R_TYPE_SEL1.2, SJ1.2
unnamed: C2-EP-DR1.2, D1.1 (K), D6.2 (A)
unnamed: EPD_C3.2, J3.4
unnamed: EPD_C4.2, J3.5
unnamed: EPD_C14.2, J3.18
unnamed: EPD_C15.2, J3.19
unnamed: EPD_C16.2, J3.20
unnamed: EPD_C18.2, J3.22
unnamed: EPD_C20.2, J3.24
unnamed: J5.A5 (CC1), R1_USB1.2
unnamed: J5.B5 (CC2), R2_USB1.1
OUT+: IC4.A3 (OUT+), TP_OP1.TP
OUT-: TP_ON1.TP
P0.13: C41.2, R1.1, SW_UP.2; also elsewhere on the board
P0.14: C44.2, R6.1, SW_ENT.2; also elsewhere on the board
P1.01: Q4.1 (G), R_PWR_EPD1.1; also elsewhere on the board
P1.02: C45.2, R10.1, SW_DN.2; also elsewhere on the board
PREVGH: D7.1 (K), EPD_C17.2, J3.21
PREVGL: D1.2 (A), EPD_C19.2, J3.23
RESE: J3.3, Q2.2 (S), R1_EP_DR1.2
SCK: J3.13; also elsewhere on the board
SCL: IC4.C1 (SCL), U2.7 (SCL); also elsewhere on the board
SDA: IC4.B2 (SDA), U2.8 (SDA); also elsewhere on the board
VBAT: C26.2, TP_VBAT1.TP, U2.2 (CELL), U2.3 (VDD); also elsewhere on the board
VBUS: C28.1, C35.1, D8.5 (VBUS), J5.A4_B9 (VBUS), J5.A9_B4 (VBUS); also elsewhere on the board

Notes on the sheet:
InkTime v6
2/2
Sheet:
E-Paper & Peripherals
drawn by: Văleanu Andrei
E-Paper Drive Circuit
E-Paper Display Connector
Fuel Gauge
USB C Connector & ESD Protection
Buttons
Haptic Driver

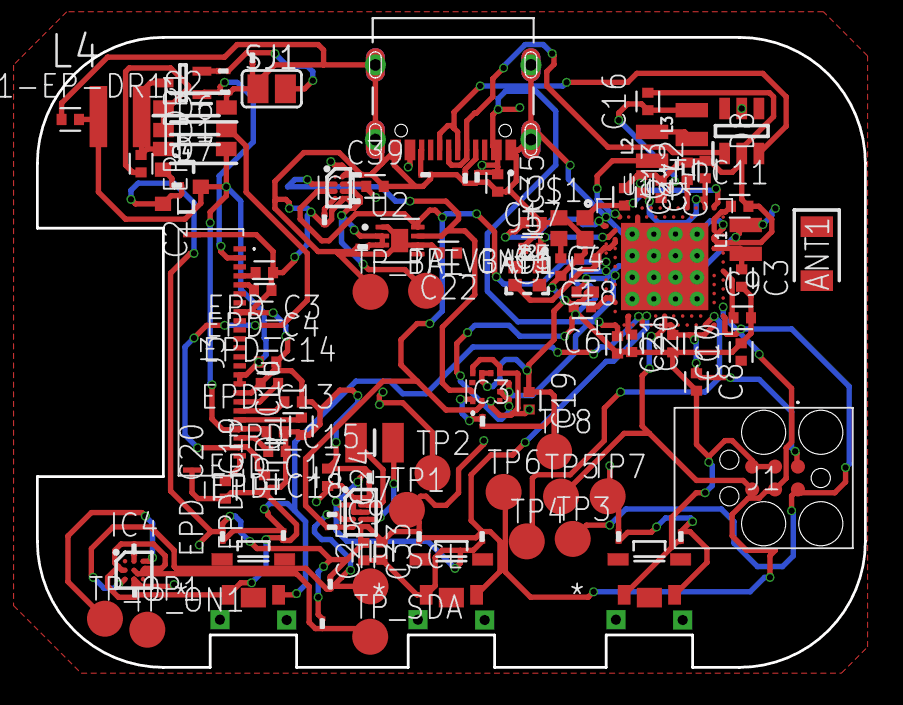
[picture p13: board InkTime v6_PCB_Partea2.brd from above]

Board: 4 copper layers, 46.0 x 35.0 mm, 105 parts (0 on the bottom side), 68 nets.

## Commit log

2026-04-10 Add hardware, mechanical, manufacturing files
    [5034802400--3DModel-STEP-56544.STEP, EVP-AKE31A--3DModel-STEP-56544.STEP, InkTime.fbrd.brd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]
2026-04-10 Finalize repository structure
    [KH-TYPE-C-16P--3DModel-STEP-269445.STEP]
2026-04-16 Align repository with OCW deliverable structure
    Remove confusing InkTime.fbrd.brd; add native .sch/.brd, schematic PDF, gerbers.zip, BOM and CPL; populate Images; add 3MF export and tools/build_ocw_deliverables.py. README documents OCW mapping, pa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
    Made-with: Cursor
    [InkTime v6_PCB_Partea2.3mf, InkTime v6_PCB_Partea2.brd, InkTime.fbrd.brd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]
2026-04-16 README: gallery, OCW docs, fusion_export merge; extend gerber script
    Add Images to README; document fusion_export CAM workflow; BOM, block diagram, nRF52840 pin summary; merge Fusion exports into gerbers.zip with precedence.
    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
2026-04-19 README: clarify via stitching vs fencing for actual layout
    Document GND vias across differently named layers as stitching; do not claim strict via fencing; fix plan and PCB notes.
    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

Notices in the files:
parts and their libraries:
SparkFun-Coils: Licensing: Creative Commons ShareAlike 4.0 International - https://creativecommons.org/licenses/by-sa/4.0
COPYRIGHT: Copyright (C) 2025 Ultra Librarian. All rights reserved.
